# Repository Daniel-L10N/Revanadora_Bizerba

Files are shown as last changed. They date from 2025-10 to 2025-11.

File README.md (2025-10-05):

# 📂 Carpeta Principal de Proyectos Técnicos

Bienvenido al repositorio central de todos los proyectos técnicos de equipos industriales. Esta carpeta madre contiene todos los desarrollos, prototipos y documentación relacionada con los distintos equipos y sistemas que se irán desarrollando a lo largo del tiempo.

---

## 📋 Propósito

La finalidad de esta carpeta es centralizar todos los archivos, códigos, esquemas y documentación de los distintos proyectos técnicos que se vayan creando. Esto permitirá un acceso rápido y organizado, facilitando la replicación, el mantenimiento y la mejora continua de los sistemas.

---

## 🧩 Estructura del Repositorio

- **/rebanadora**: Contiene todos los archivos específicos del proyecto de la máquina rebanadora, incluyendo esquemas, código y pruebas.

- **/otros_proyectos**: Carpeta para futuros desarrollos, donde se irán añadiendo nuevos proyectos, cada uno con su propia documentación.

- **/documentacion**: Archivos generales, guías de diseño, análisis de componentes, y mejores prácticas.

---

## 🔍 Contenido del Proyecto

Cada subproyecto incluirá:

- **Código fuente**: Archivos de firmware con comentarios detallados.
- **Esquemas eléctricos**: Diagramas y planos de conexión.
- **Documentación técnica**: Descripciones de componentes, análisis y guías de implementación.
- **Imágenes**: Fotos, capturas de pantalla y diagramas.

---

## 🚀 Futuro y Expansión

Esta carpeta madre está diseñada para ser **un centro de referencia** para todos los proyectos técnicos futuros. Con el tiempo, se irán agregando más proyectos y mejorando la documentación para mantener todo bien organizado y accesible.

---

## 🔒 Privacidad y Acceso

Este repositorio es **privado** y está destinado exclusivamente para uso interno y de trabajo. No se compartirá información fuera del equipo.

---

## 📅 Historial de Versiones

Mantén un registro de cambios y mejoras

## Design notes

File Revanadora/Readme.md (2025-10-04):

# 🧾 Proyecto: Tarjeta de Control para Rebanadora Industrial

## 🟢 Resumen General

- **Motivo**: Reemplazo de tarjeta original quemada.
- **Controlador principal**: ESP32-WROOM-DA montado sobre placa tipo PLC.
- **Alimentación general**: Fuente externa de 12 V DC.
- **Motor**: Monofásico 110 V AC, 1/3 HP (~250 W).
- **Control de potencia**: Relé de estado sólido (SSR) activado por relé intermedio de 12 V.
- **Entradas protegidas**: 3 señales aisladas con optoacopladores.
- **Indicador visual**: LED de 12 V controlado por relé.

---

## ⚡ Alimentación

| Componente | Voltaje | Fuente | Observaciones |
|---|---|---|---|
| Placa PLC ESP32 | 12 V DC | Fuente externa | Regulación interna a 3.3 V incluida |
| Relés (x2) | 12 V DC | Fuente externa | Uno para motor, otro para LED |
| Sensor Hall | 12 V DC | Fuente externa | Detecta movimiento |
| LED indicador | 12 V DC | Fuente externa | Encendido cuando motor está activo |

### 🔒 Protecciones recomendadas

- Fusible de entrada: 2 A lento en línea de 12 V DC.
- Fusible de salida: 5 A rápido en línea de motor (antes del SSR).
- Diodos flyback en bobinas de relés.
- Capacitores de filtrado en entrada de fuente (1000 µF + 100 nF).
- Varistor en línea de 110 V AC (protección contra picos).

---

## 🧠 Controlador – ESP32-WROOM-DA

- Montado sobre placa PLC con:
  - Regulador interno.
  - Optoacopladores para entradas.
  - Relés integrados (6 disponibles, se usan 2).
- Alimentado directamente con 12 V DC.
- Comunicación posible por WiFi/Bluetooth (opcional).

---

## 🔘 Entradas digitales (aisladas con optoacopladores)

| Entrada | Tipo | Función | Estado lógico en ESP |
|---|---|---|---|
| Botón arranque | NA | Inicia ciclo, activa motor | HIGH cuando presionado|
| Botón paro | NC | Detiene motor inmediatamente | LOW cuando presionado |
| Final de carrera | NC | Apaga motor al llegar a posición 0 | LOW cuando activado |

---

## 🧲 Sensor de efecto Hall

- Detecta campo magnético en eje de brazo.
- Señal digital enviada al ESP32.
- Si no hay pulsos por 15 s → sistema entra en modo standby (motor apagado).

---

## 🔁 Salidas digitales

| Salida | Tipo | Controlador | Función |
|---|---|---|---|
| Relé motor | Relé 12 V| ESP32 | Activa SSR → motor ON/OFF |
| Relé LED | Relé 12 V| ESP32 | Enciende LED cuando motor está activo |

---

## 💡 Indicadores

- LED de 12 V conectado a relé.
- Encendido solo cuando el motor está en funcionamiento.

---

## 🔄 Lógica de operación (flujo básico)

```plaintext
INICIO
↓
Esperar botón de arranque
↓
Si ARRANQUE presionado → activar relé motor + relé LED
↓
Mientras motor encendido:
    - Si PARO presionado → apagar motor + LED
    - Si FINAL DE CARRERA activado → apagar motor + LED
    - Si no hay pulsos Hall por 15 s → apagar motor + LED
↓
Esperar nuevo arranque

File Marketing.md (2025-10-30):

### Control Modular MX

Diseñamos y fabricamos sistemas de control industrial modulares, seguros y documentados.

- Automatización de maquinaria
- PLCs personalizados con microcontroladores
- Relés, sensores y fuentes integradas
- Documentación profesional en Markdown
- Diseño ético y estético de PCBs

📍 Hecho en México. Pensado para el mundo.

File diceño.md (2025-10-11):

🧱 Diseño de hardware – PLC con ATmega328
🔧 Microcontrolador
ATmega328P-PU (montado directo en placa)

Cristal de 16 MHz conectado a XTAL1 y XTAL2

2 capacitores cerámicos de 22 pF entre cada pin del cristal y GND

Resistencia de 10 kΩ entre RESET y Vcc

Capacitor de 100 nF entre Vcc y GND (desacoplo)

⚡ Fuente de alimentación
Entrada: 12 V DC desde bornera

Regulador lineal: 7805 para convertir 12 V → 5 V

Condensadores:

100 µF entre entrada 12 V y GND

100 µF entre salida 5 V y GND

Salida: 5 V para alimentar ATmega328 y lógica

🟢 Entradas optoacopladas (PC817 ×4)
Cada entrada incluye:

Resistencia limitadora: 1 kΩ–2.2 kΩ en serie con el LED del opto

LED interno del optoacoplador conectado a señal externa

Salida del opto conectada al pin digital del ATmega328

Pull-down externo de 10 kΩ si se requiere estabilidad

Entrada	Pin ATmega328	Función lógica
btArranque	D2	Botón de arranque
btApagado	D3	Botón de apagado
finalCarrera	D4	Final de recorrido
sensorHall	D5	Sensor de efecto Hall
🔴 Salidas de relé (Steren 12 V 5 A ×2)
Cada salida incluye:

Transistor NPN (ej. 2N2222 o BC547)

Resistencia de base: 1 kΩ entre pin ATmega y base

Colector conectado al relé

Emisor a GND

Diodo 1N4007 en paralelo con bobina del relé (protección contra contracorriente)

Relé alimentado directamente con 12 V

Salida	Pin ATmega328	Función lógica
releMotor	D8	Motor principal
releFoco	D9	Foco piloto
💡 LED de estado
Pin D13 conectado a LED con resistencia de 330 Ω

Indica encendido o estado lógico del sistema

🧩 Conectores y distribución
Bornera de entrada 12 V con protección (fusible o PPTC)

Borneras para entradas optoacopladas (señales externas)

Borneras para salidas de relé (NO/NC/COM)

Header ISP opcional para programación del ATmega328

🧾 Esquema modular en Proteus
Organiza el diseño así:

🔋 Izquierda: fuente de 12 V, regulador 7805, capacitores

🧠 Centro: ATmega328, cristal, LED, pines etiquetados

🟢 Arriba: entradas optoacopladas (PC817)

🔴 Abajo: transistores y relés Steren con diodos

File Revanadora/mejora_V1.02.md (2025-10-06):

## Sensor Inductivo

En caso de utilizar un sensor inductivo, este se colocará en el centro del equipo. Esto reducirá las probabilidades de que el brazo de carga pase sin ser detectado. El sensor detectará el paso del brazo cuando este se desplace frente a él.

#### Para usar el sensor inductivo, se recomienda emplear la función `millis()` en lugar de `delay()`. Esto permitirá gestionar el tiempo de manera más eficiente y evitará bloqueos en el programa.

#### para usar el sensor a un voltaje mas alto al del microcontrolador se puede usar un optoacoplador o un transistor NPN, preferentemente un optoacoplador para aislar el microcontrolador del voltaje mas alto.

## Codigo de colores: 
##### Azul: GND Negativo
##### Marón: VCC Positivo
##### Negro: Señal

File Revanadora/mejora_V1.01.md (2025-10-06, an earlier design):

# Mejora V1.1: Implementación de Sensores para el Eje Guía

La siguiente mejora para el equipo rebanadora consiste en la implementación de un sensor para detectar el desplazamiento del brazo de carga sobre el eje guía. Esto se logrará utilizando un sensor de efecto Hall o, en su defecto, un sensor inductivo. A continuación, se detalla la propuesta:

## Sensor de Efecto Hall

El sensor de efecto Hall detectará variaciones en el campo magnético. Estas variaciones permitirán determinar si el brazo de carga se está desplazando sobre el eje guía. Para implementar esta solución:

1. **Configuración del sensor**: Se establecerán rangos de variación del campo magnético que indiquen el movimiento del brazo.
2. **Limitaciones del hardware**: Si el hardware no permite medir con precisión las variaciones del campo magnético, se optará por un sensor inductivo.

## Sensor Inductivo

En caso de utilizar un sensor inductivo, este se colocará en el centro del equipo. Esto reducirá las probabilidades de que el brazo de carga pase sin ser detectado. El sensor detectará el paso del brazo cuando este se desplace frente a él.

### Código de Ejemplo: Sensor Inductivo con `millis()`

El siguiente código utiliza un sensor inductivo para detectar el paso del brazo. Se emplea la función `millis()` para gestionar el tiempo y evitar bloqueos en el programa.

```cpp
const int sensorPin = 2; // Pin digital conectado al sensor inductivo
const int ledPin = 13;   // LED indicador (opcional)
bool brazoDetectado = false;
unsigned long tiempoAnterior = 0;
const unsigned long intervalo = 500; // Tiempo mínimo entre detecciones (en ms)

void setup() {
    pinMode(sensorPin, INPUT);
    pinMode(ledPin, OUTPUT);
    Serial.begin(9600);
}

void loop() {
    int estadoSensor = digitalRead(sensorPin);
    unsigned long tiempoActual = millis();

    // Detectar si el brazo pasa frente al sensor
    if (estadoSensor == HIGH && !brazoDetectado && (tiempoActual - tiempoAnterior >= intervalo)) {
        brazoDetectado = true;
        tiempoAnterior = tiempoActual;
        digitalWrite(ledPin, HIGH); // Enciende el LED (opcional)
        Serial.println("Brazo detectado");
    }

    // Restablecer el estado cuando el brazo ya no está frente al sensor
    if (estadoSensor == LOW) {
        brazoDetectado = false;
        digitalWrite(ledPin, LOW); // Apaga el LED (opcional)
    }
}
```

### Consideraciones

- **Colocación del sensor**: Asegúrate de que el sensor esté correctamente alineado con el brazo de carga.
- **Pruebas y calibración**: Realiza pruebas para ajustar los rangos de detección y minimizar errores.
- **Seguridad**: Implementa medidas de seguridad para evitar daños al equipo o al operador.

Con esta mejora, se espera optimizar el funcionamiento del equipo rebanadora y garantizar una detección precisa del movimiento del brazo de carga.

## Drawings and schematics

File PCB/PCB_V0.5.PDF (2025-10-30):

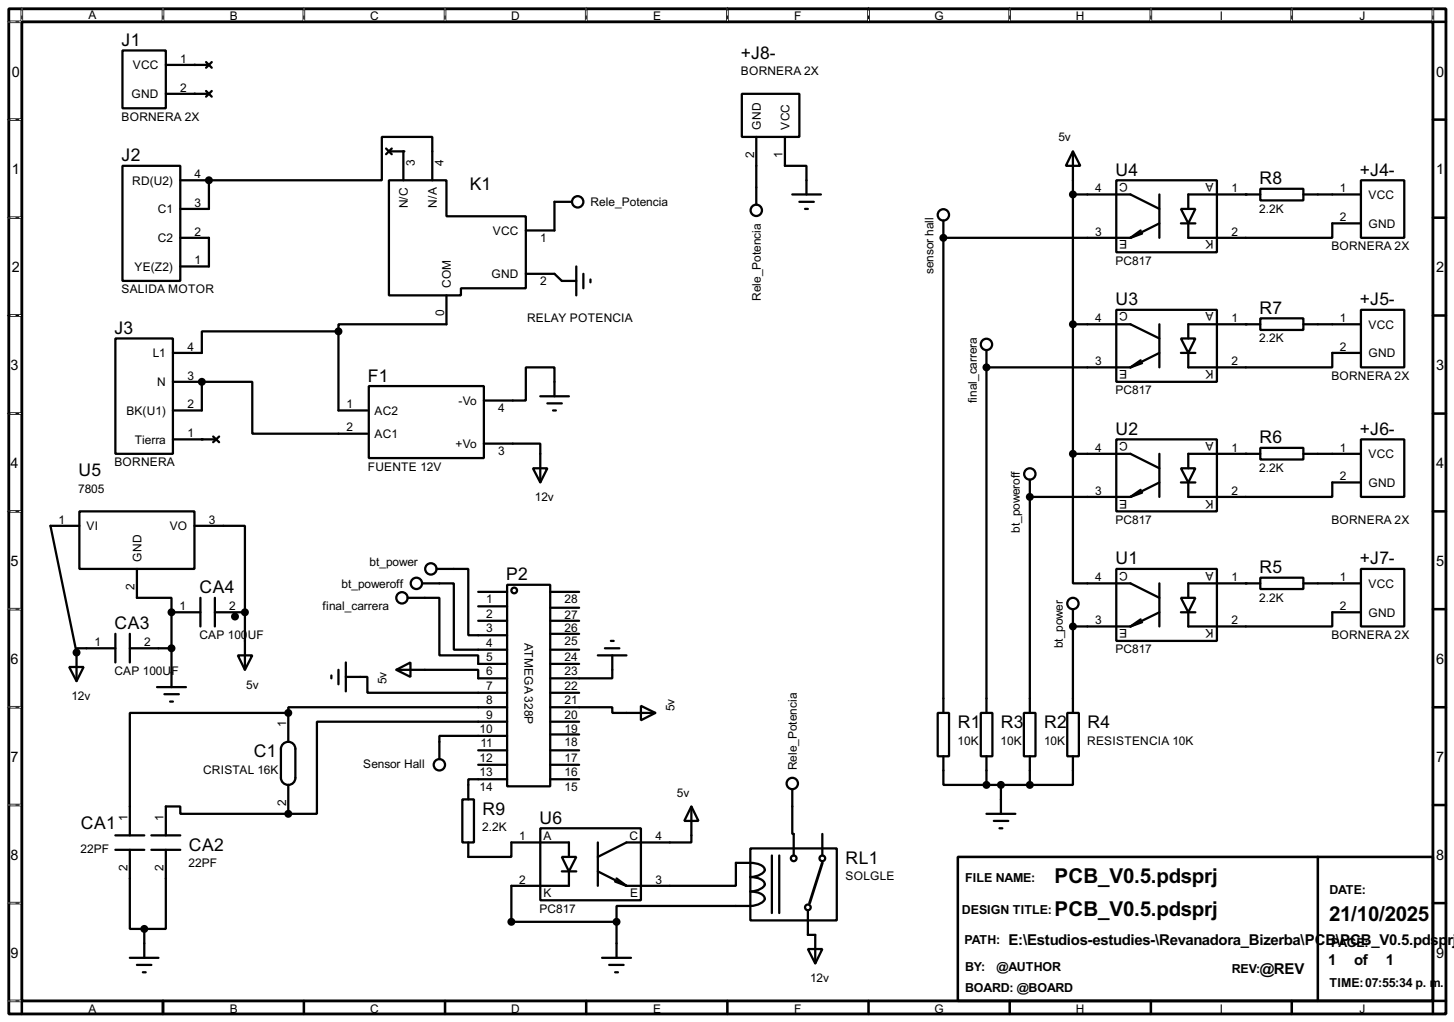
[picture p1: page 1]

2 | | 27
3 | | 26
4 | | 25
5 | | 24
6 | | 23
7 | | 22

10 | 19
11 | 18

PATH: E:\Estudios-estudies-\Revanadora_Bizerba\PCB\PCB_V0.5.pdsprj

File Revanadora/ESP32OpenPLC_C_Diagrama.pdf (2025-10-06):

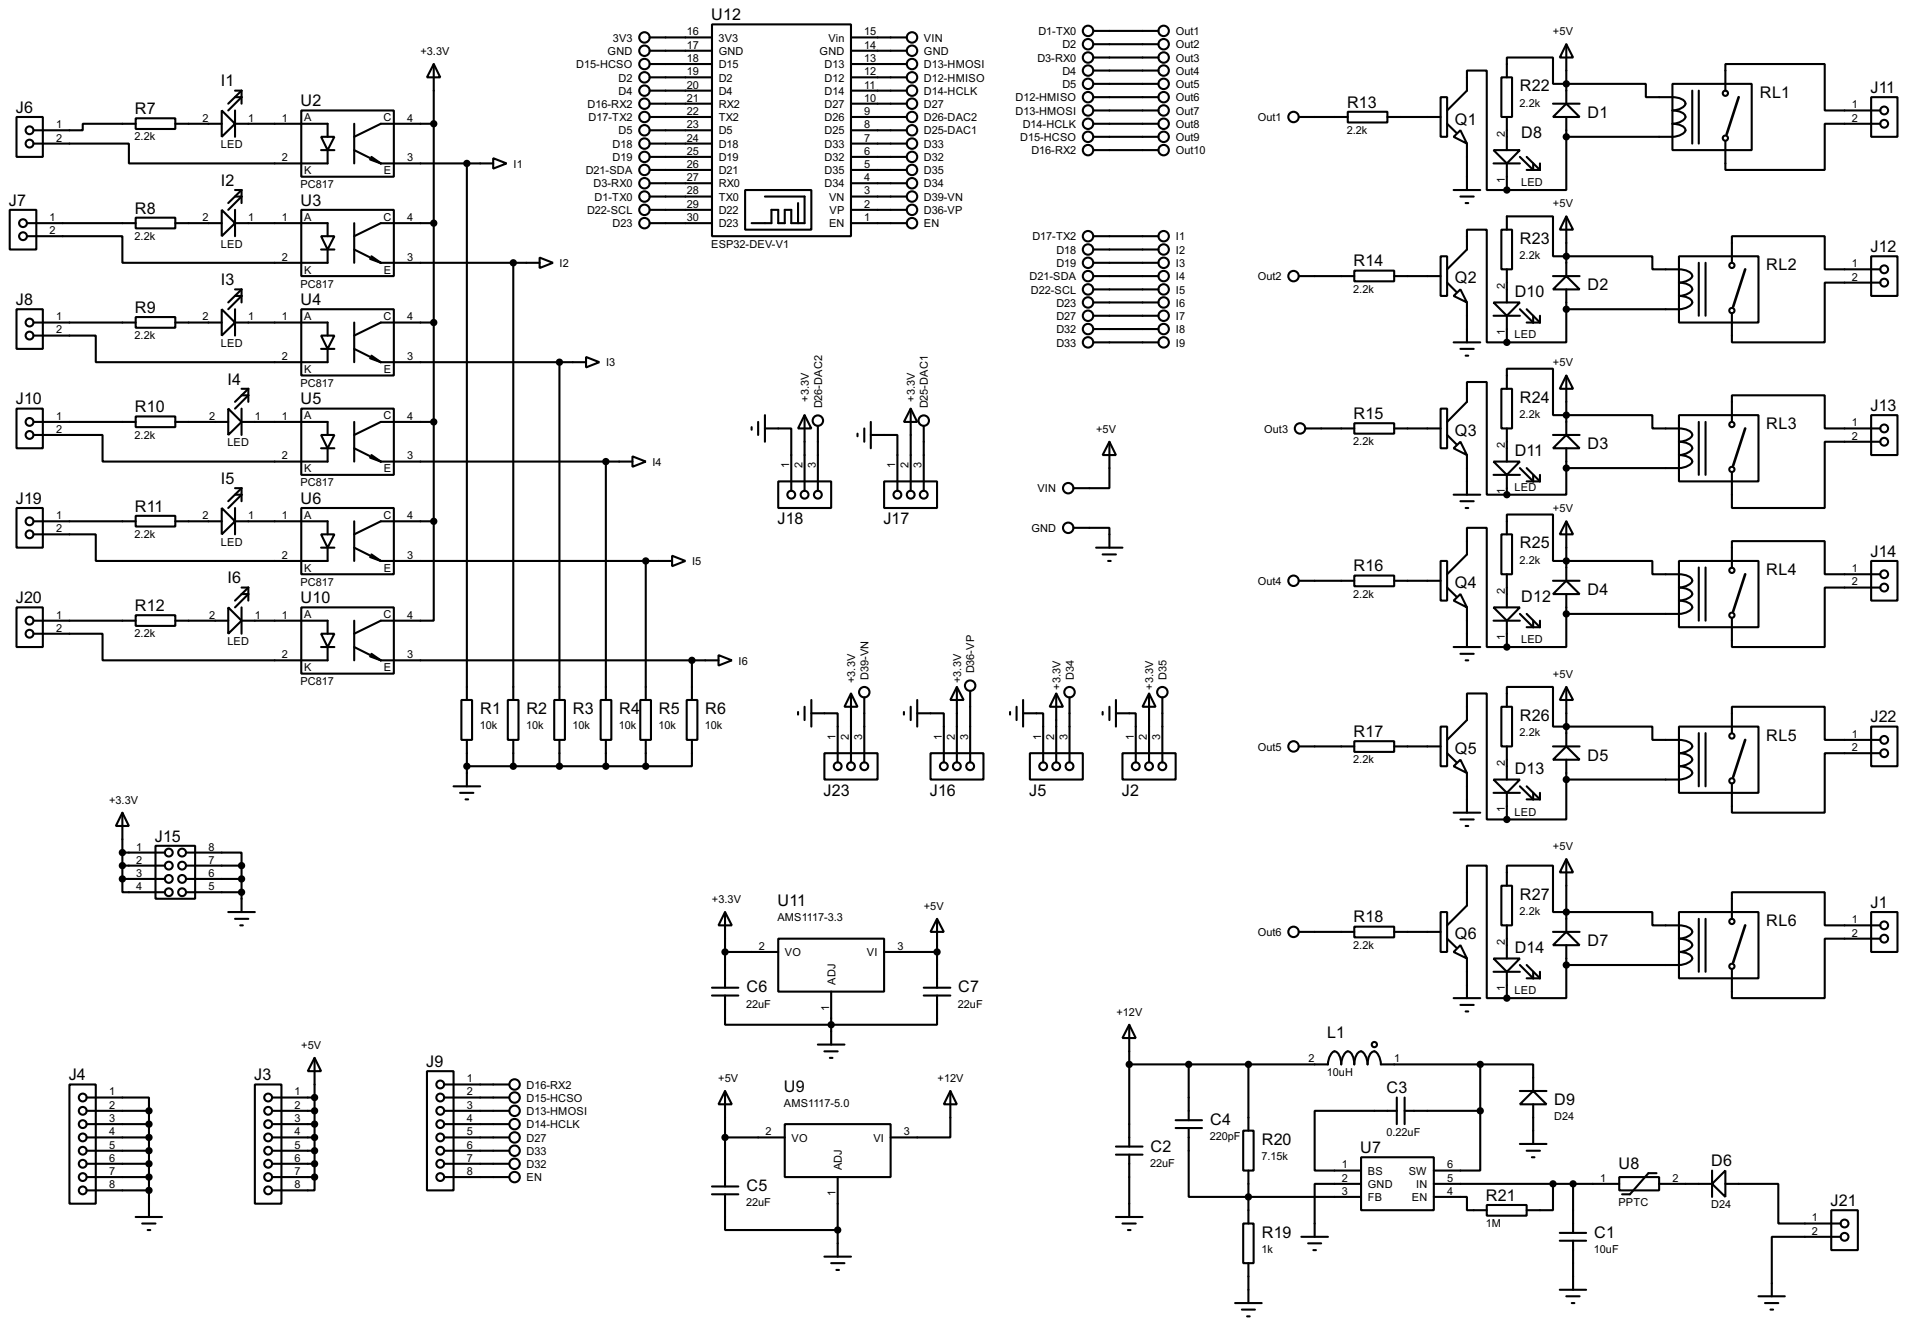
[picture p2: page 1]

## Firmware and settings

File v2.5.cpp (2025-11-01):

// === CONFIGURACIÓN DE PINES ===
const int releMotor = 8;
const int entradasOpto[4] = {2, 3, 4, 5};

const int btArranque      = entradasOpto[0]; // D2
const int btApagado       = entradasOpto[1]; // D3
const int finalDeCarrera  = entradasOpto[2]; // D4
const int sensorHall      = entradasOpto[3]; // D5

// === TEMPORIZADORES ===
unsigned long tiempoInicial = 0;
unsigned long tiempoEstablecido = 20000;
unsigned long tiempoActual = 0;

// Estado lógico del relé
bool releActivo = false;

void setup() {
  // Entradas con resistencias pull-down físicas
  pinMode(btArranque, INPUT);
  pinMode(btApagado, INPUT);
  pinMode(finalDeCarrera, INPUT);
  pinMode(sensorHall, INPUT);

  // Salida del relé
  pinMode(releMotor, OUTPUT);
  digitalWrite(releMotor, LOW);
}

void loop() {
  // Condición de arranque
  if (digitalRead(btArranque) == HIGH &&
      digitalRead(btApagado) == HIGH &&
      digitalRead(finalDeCarrera) == HIGH) {

    digitalWrite(releMotor, HIGH);
    releActivo = true;
    tiempoInicial = millis();
  }

  // Reinicio de temporizador si hay señal del sensor Hall
  if (digitalRead(sensorHall) == HIGH && releActivo) {
    tiempoInicial = millis();
  }

  // Condiciones de apagado si el relé está activo
  if (releActivo) {
    tiempoActual = millis();

    if (digitalRead(btApagado) == LOW ||
        digitalRead(finalDeCarrera) == LOW ||
        (tiempoActual - tiempoInicial >= tiempoEstablecido)) {

      digitalWrite(releMotor, LOW);
      releActivo = false;
    }
  }
}

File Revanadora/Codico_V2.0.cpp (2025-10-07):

// Pines conectados a los relés..
const int reles[6] = {1, 2, 3, 4, 5, 12};
// Pines conectados a las entradas digitales de los optocopladores..
const int entradasOpto[6] = {17, 18, 19, 21, 22, 23}; 

//Definiendo TIMERS...
unsigned long tiempoInicial = 0;
unsigned long tiempoEstablecido = 10000;
unsigned long tiempoActual;

//Definiendo botonera
const int btArranque = entradasOpto[0]; // Entrada digital (btn de arranque)
const int btApagado = entradasOpto[1];  // Entrada digital (btn de apagar)

//Definiendo Sistema de Seguridad
const int finalDeCarrera = entradasOpto[2]; // Entrada digital (btn de finalizacion de uso del equipo)
const int sensorHall = entradasOpto[3]; // Implementacion del sonsor de efecto hall

void setup() {


  // Configura entrada con resistencia pull-up - pulldown interna
  pinMode(btArranque, INPUT_PULLDOWN); // LOW cuando no presionado, con proteccion contra pin flotante.
  pinMode(finalDeCarrera, INPUT_PULLDOWN);
  pinMode(sensorHall, INPUT_PULLDOWN);
  pinMode(btApagado, INPUT_PULLDOWN);

  // Configura los relés como salidas
  for (int i = 0; i < 2; i++) {
    pinMode(reles[i], OUTPUT);
    digitalWrite(reles[i], LOW); // Inicializacion el nivel bajo LOW
  }
  for (int i = 2; i < 6; i++){ // INICIALIZANDO RELES PARA EVITAR FALLOS EN LOGICA ELECTRICA.
    pinMode(reles[i], OUTPUT);

  }
}

void loop() {
  

  if (digitalRead(btArranque) == HIGH && digitalRead(btApagado)== HIGH && digitalRead(finalDeCarrera) == HIGH) { // Botón presionado ejecutar. y no esta precionado el de apagado y la maquina no se encuentra en estado de descanso.

    digitalWrite(reles[0], HIGH); // Activar relé numero 1, que activa rele de motor
    digitalWrite(reles[1], HIGH); // Activar rele nuemro 2 de foco piloto
    tiempoInicial = millis(); // Actualizando el arranque inicial.

  }
  if (digitalRead(sensorHall) == HIGH){
    tiempoInicial = millis();
  }
  
  if (digitalRead(reles[0]) == HIGH && digitalRead(reles[1] == HIGH)){ //Bucle de apagado.
    tiempoActual = millis();

    if (digitalRead(btApagado) == LOW){ // Ejecutar si se preciona el boton apagado
  
    digitalWrite(reles[0], LOW); 
    digitalWrite(reles[1], LOW);
    
    }else if (digitalRead(finalDeCarrera) == LOW){// Ejecutar si se llega al 0 en la linea de uso.

    
    digitalWrite(reles[0], LOW);
    digitalWrite(reles[1], LOW); 
    
    }
    // Detencion por tiempo transcurrido
    else if((tiempoActual - tiempoInicial) >= tiempoEstablecido){
    digitalWrite(reles[0], LOW);
    digitalWrite(reles[1], LOW); 
    
    }
  }
   

}

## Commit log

2025-10-05 terminando la creacion del codigo base vercion 1.0 estable para revanadora
2025-10-05 moviendo el archivo a su sugar
2025-10-06 agg mejora #2 sensor inductivo
2025-10-07 Como esatableser el sensor
2025-10-07 creada la version 2.0 con sistema de seguridad por sensor hall y taimers
2025-11-01 version para atmega
